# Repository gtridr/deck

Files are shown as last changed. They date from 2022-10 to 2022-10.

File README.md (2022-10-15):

# deck
An integrated instrument &amp; control surface based on norns

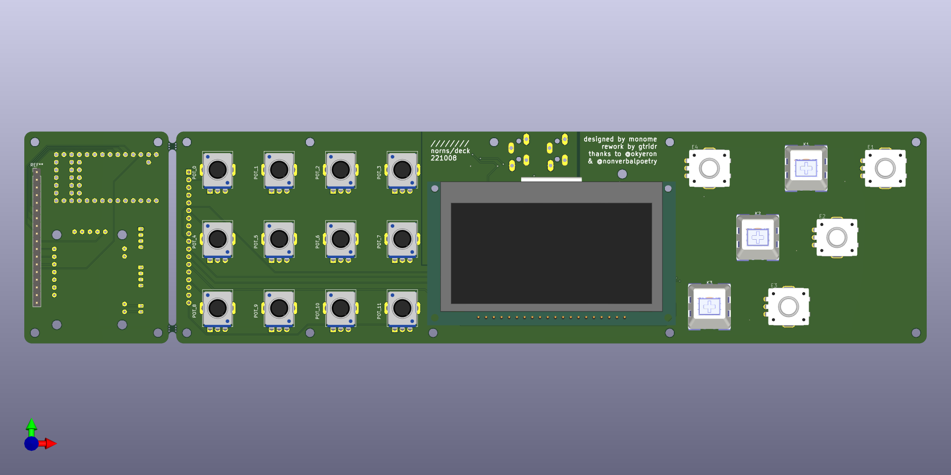
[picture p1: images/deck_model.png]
3D


## Credits & Licensing

Starting things off: this project is licensed as a derivative work under GPL-3.0. All due credits to the following individuals & projects:

 - The core audio codec & voltage regulation design are unmodified from the 210330 revision of the [norns shield](https://github.com/monome/norns-shield) save for some rerouting & cleanup

 - The raspberry pi image is a very lightly modified fork of the mainline norns codebase, with just a few tweaks to map the 4th encoder, serial pins for MICROMIDITRS, and soft shutdown via ATXRaspi.

 - The teensy firmware is a fork of Okyeron's [DIY grid](https://github.com/okyeron/neotrellis-monome) firmware. All credit for the grid emulation goes to him; I've only added what was necessary to get the potentiometers working over USB MIDI

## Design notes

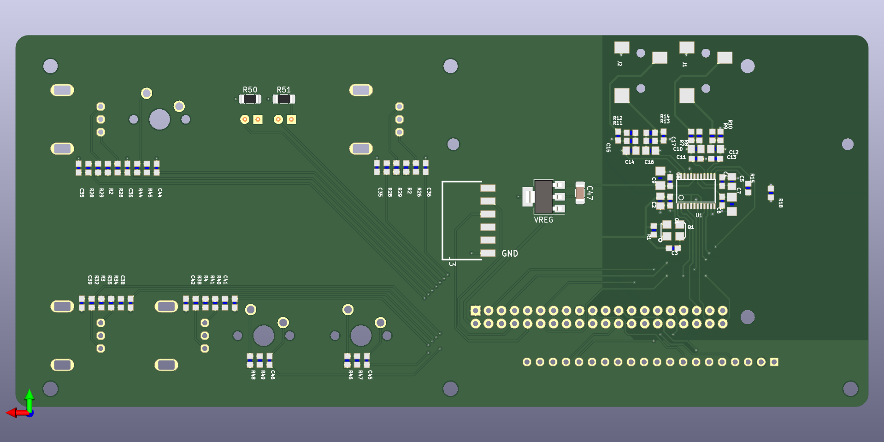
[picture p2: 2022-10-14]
images/Original/3d_back.png

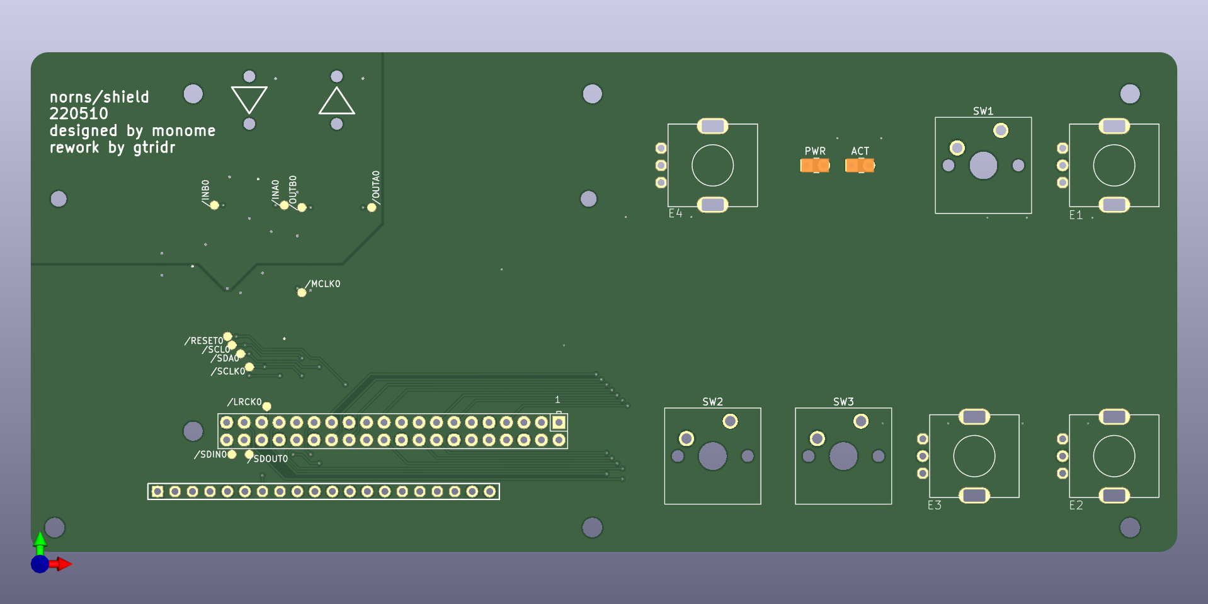
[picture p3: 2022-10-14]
images/Original/3d.png

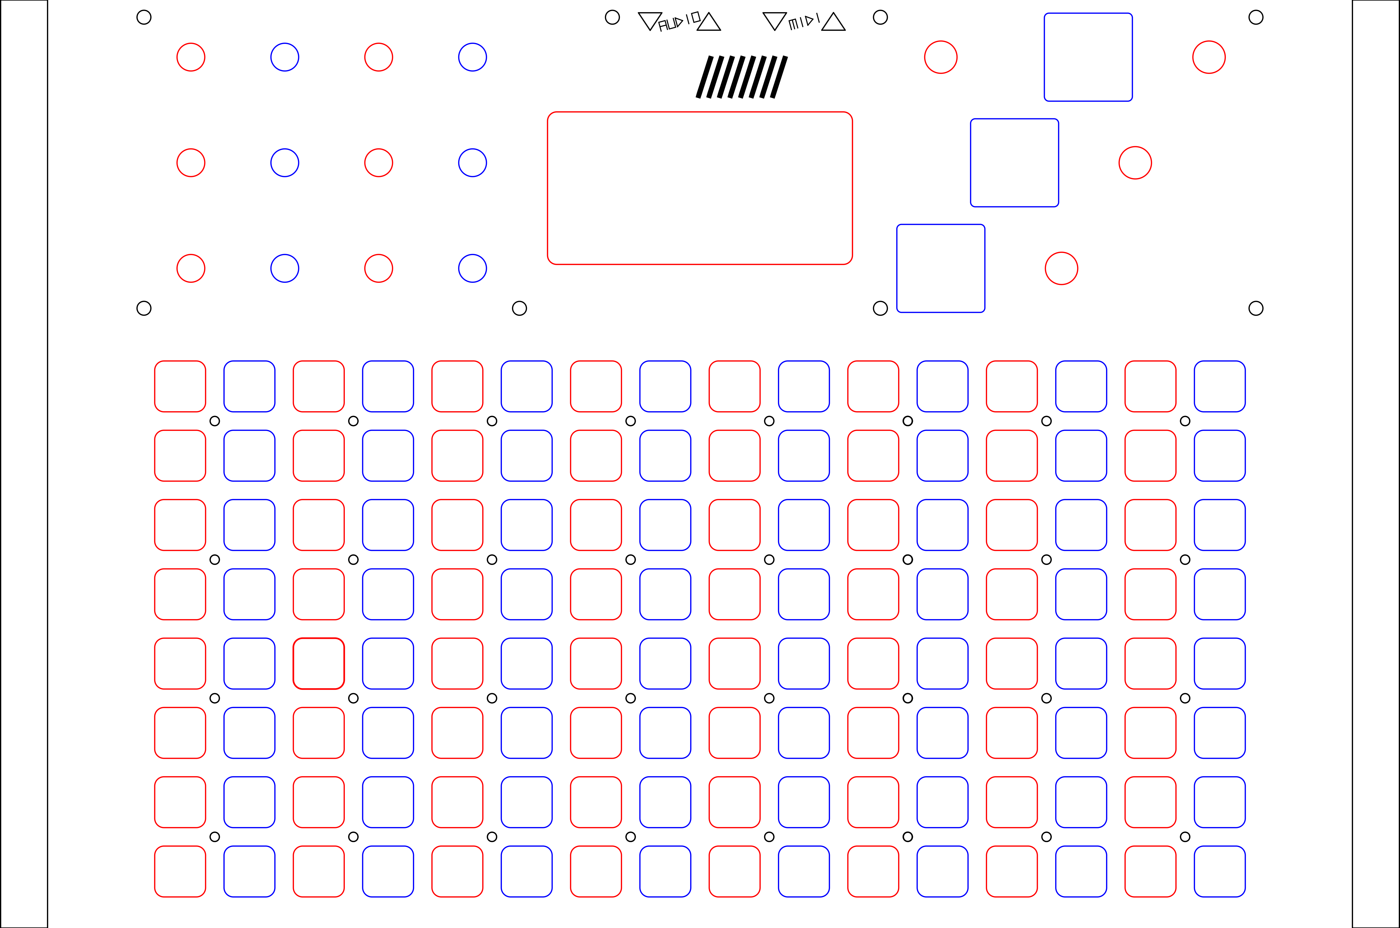
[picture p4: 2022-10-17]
images/deck_panel.png

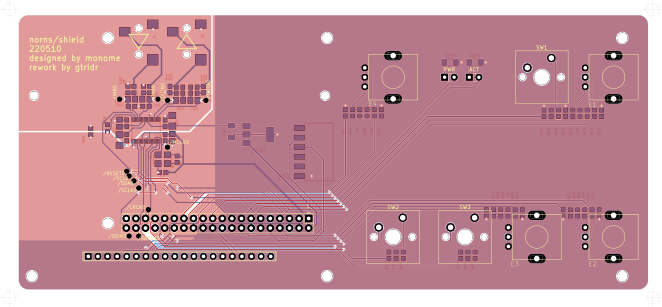
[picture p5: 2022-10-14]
images/Original/g7782.png

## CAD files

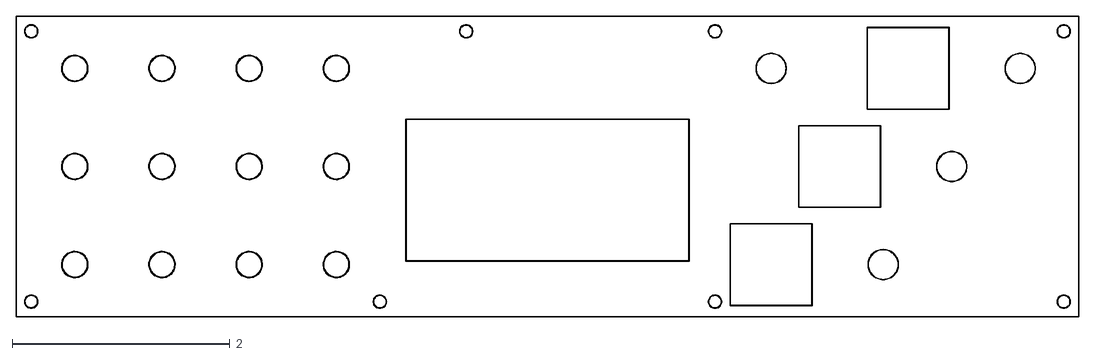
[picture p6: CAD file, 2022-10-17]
Enclosure/deck_outline.dxf
9.75 x 2.76

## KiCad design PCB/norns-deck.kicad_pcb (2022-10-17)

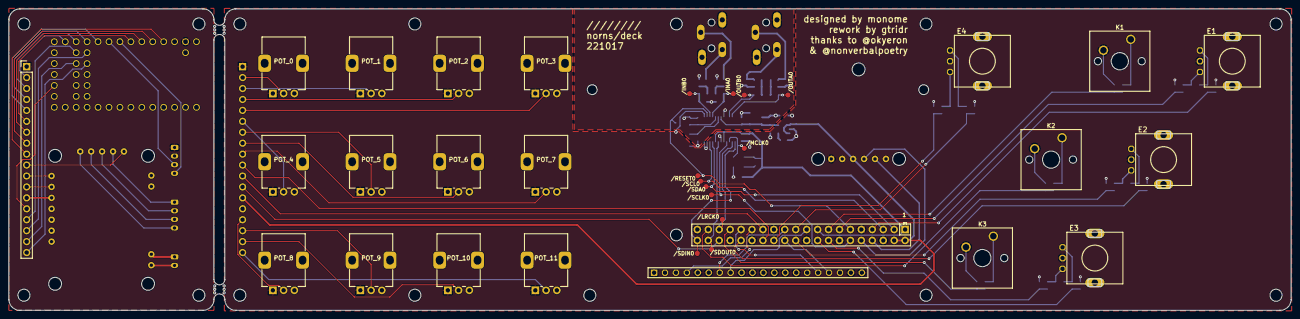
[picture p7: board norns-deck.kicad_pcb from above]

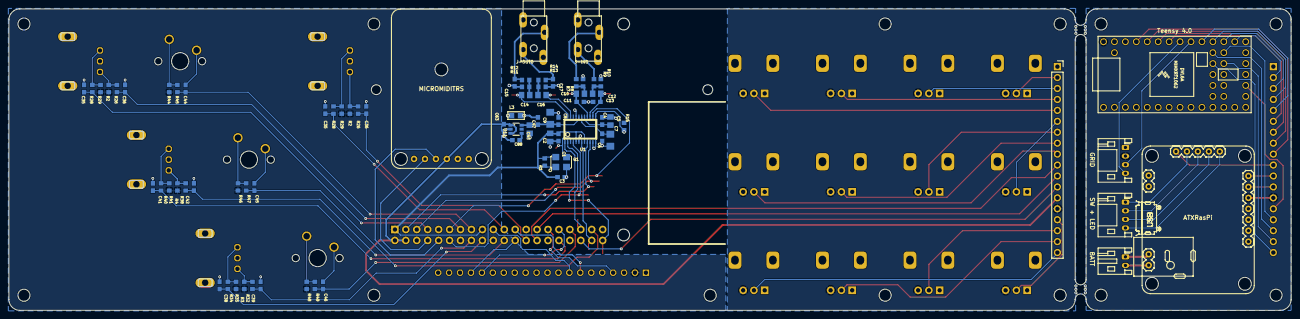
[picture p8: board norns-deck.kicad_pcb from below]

Board: 2 copper layers, 297.8 x 70.0 mm, 118 parts (76 on the bottom side), 80 nets.

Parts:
/INA0: TPTP12R; TP12R
/INB0: TPTP12R; TP12R
/LRCK0: TPTP12R; TP12R
/MCLK0: TPTP12R; TP12R
/OUTA0: TPTP12R; TP12R
/OUTB0: TPTP12R; TP12R
/RESET0: TPTP12R; TP12R
/SCL0: TPTP12R; TP12R
/SCLK0: TPTP12R; TP12R
/SDA0: TPTP12R; TP12R
/SDIN0: TPTP12R; TP12R
/SDOUT0: TPTP12R; TP12R
ATXRasPi: ATXRaspi
BATT: JST_PH_S2B-PH-K_1x02_P2.00mm_Horizontal
C1, C4, C6, C8, C47, C63: 100n; C0603
C2, C5, C10, C12, C43: 10u; C0805
C3, C35, C35#2, C36, C36#2, C38, C39, C41, C42, C44, C45, C46, C88: 10n; C0603
C7, C9: 47u; C1206
C11, C13: 220p COG; C0603
C14, C16: 3.3u; C0805
C15, C17: 2700p COG; C0603
DAUGHTERBOARD: PinSocket_1x18_P2.54mm_Vertical
E1: ENC1; PEC11RN
E2: ENC2; PEC11RN
E3: ENC3; PEC11RN
E4: ENC4; PEC11RN
GRID: JST_PH_S4B-PH-K_1x04_P2.00mm_Horizontal
J-IN0: JACK-TRS-SW; JACK4832.2330
J-OUT0: JACK-TRS-SW; JACK4832.2330
K1, K2, K3: SW_Cherry_MX_1.00u_PCB_NO_OUTLINE; SW_Cherry_MX_1.00u_PCB_NARROW_OUTLINE
L3: FERRITE; L0805
MICROMIDITRS: MICROMIDITRS
MNT: mounting hole
MNT#2, MNT#3, MNT#4, MNT#5, MNT#6: mounting hole
POT_0, POT_1, POT_2, POT_3, POT_4, POT_5, POT_6, POT_7, POT_8, POT_9, POT_10, POT_11: Potentiometer_Alps_RK09K_Single_Vertical
Q1: ASFL-12.288mhz; ASF
R1, R2, R2#2, R3, R4, R8, R10, R11, R13, R15, R26, R26#2, R28, R28#2, R29, R29#2, R32, R34, R35, R38, R40, R41, R44, R45, R46, R47, R48, R49: 10k; R0603
R7, R9: 4.99k; R0603
R12, R14: 590; R0603
SW + LED: JST_PH_S4B-PH-K_1x04_P2.00mm_Horizontal
Teensy 4.0: Teensy 4.0; Teensy40
U1: CS4270; TSSOP24
U11: TPS793; SSOP6
U$1: OLED128X64; OLED-ALEPH
X1: RASPI_BOARD_B+#_E3; RASPI_BOARD_B+_EDGES_3DRILL
mouse-bite-2.54mm-slot, mouse-bite-2.54mm-slot#2: VAL**; mouse-bite-2.54mm-slot

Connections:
+3V3: C1.1, C2.1, C3.1, Q1.4, R1.1, R2.2, R2#2.2, R3.2, R4.2, R29.2, R29#2.2, R35.2, R41.2, R44.1, R46.1, R48.1, U1.5, U1.8, U$1.2, X1.1, X1.17
+5V: ATXRasPi.9, C63.1, DAUGHTERBOARD.13, GRID.2, MICROMIDITRS.3, Teensy 4.0.33, U11.1, U11.3, X1.2, X1.4
A1: C35#2.1, R28#2.2, X1.7
A2: C41.1, R40.2, X1.32
A3: C38.1, R34.2, X1.18
A4: C35.1, R28.2, X1.21
A5V: C8.1, C9.1, C43.1, C47.1, U1.19, U11.6
AGND: C4.2, C5.2, C6.2, C7.2, C8.2, C9.2, C11.2, C13.2, C15.2, C17.2, C47.2, J-IN0.S, J-IN0.SW, J-OUT0.S, J-OUT0.SW, L3.1, R8.2, R10.2, R11.2, R13.2, U1.20
ATX1: DAUGHTERBOARD.10, X1.28
ATX2: DAUGHTERBOARD.11, X1.27
ATX3: DAUGHTERBOARD.12, X1.36
B1: C36.1, R26.2, X1.13
B2: C42.1, R38.2, X1.22
B3: C39.1, R32.2, X1.16
B4: C36#2.1, R26#2.2, X1.26
BAT+: ATXRasPi.14, BATT.2
BAT-: ATXRasPi.15, BATT.1
CE0: U$1.17, X1.24
GND: C1.2, C2.2, C3.2, C35.2, C35#2.2, C36.2, C36#2.2, C38.2, C39.2, C41.2, C42.2, C43.2, C44.2, C45.2, C46.2, C63.2, C88.2, DAUGHTERBOARD.1, E1.GND, E2.GND, E3.GND, GRID.1, K1.2, K2.2, K3.2, L3.2, MICROMIDITRS.1, POT_0.1, POT_1.1, POT_2.1, POT_3.1, POT_4.1, POT_5.1, POT_6.1, POT_7.1, POT_8.1, POT_9.1, POT_10.1, POT_11.1, Q1.2, R15.2, Teensy 4.0.32, U1.6, U1.11, U1.12, U1.13, U11.2, U$1.1, U$1.5, U$1.6, U$1.9, U$1.10, U$1.11, U$1.12, U$1.13, U$1.14, U$1.19, U$1.20, X1.6, X1.9, X1.14, X1.20, X1.25, X1.30, X1.34, X1.39
INA: /INA0.TP, C10.1, C11.1, U1.16
INB: /INB0.TP, C12.1, C13.1, U1.15
K1: C44.1, R45.2, X1.15
K2: C45.1, R47.2, X1.37
K3: C46.1, R49.2, X1.33
LED+: ATXRasPi.5, SW + LED.4
LED-: ATXRasPi.4, SW + LED.3
LRCK: /LRCK0.TP, U1.2, X1.35
MCLK: /MCLK0.TP, Q1.3, U1.3
MOSI: U$1.8, X1.19
unnamed: Q1.1, R1.2
unnamed: K1.1, R44.2, R45.1
unnamed: C4.1, C5.1, U1.17
unnamed: C6.1, C7.1, U1.18
unnamed: J-IN0.R, R7.2
unnamed: C10.2, R7.1, R8.1
unnamed: C12.2, R9.1, R10.1
unnamed: J-IN0.T, R9.2
unnamed: C16.2, R13.1, R14.1
unnamed: C14.2, R11.1, R12.1
unnamed: C15.1, J-OUT0.R, R12.2
unnamed: C17.1, J-OUT0.T, R14.2
unnamed: E1.A, R28#2.1, R29#2.1
unnamed: E1.B, R2.1, R26.1
unnamed: E3.B, R3.1, R32.1
unnamed: E3.A, R34.1, R35.1
unnamed: E2.B, R4.1, R38.1
unnamed: E2.A, R40.1, R41.1
unnamed: E4.A, R28.1, R29.1
unnamed: E4.B, R2#2.1, R26#2.1
unnamed: C88.1, U11.4
OUTA: /OUTA0.TP, C14.1, U1.23
OUTB: /OUTB0.TP, C16.1, U1.22
O_DC: U$1.4, X1.29
O_RESET: U$1.16, X1.31
R-CODEC: /RESET0.TP, R15.1, U1.14, X1.11
RX: MICROMIDITRS.4, X1.10
SCK: U$1.7, X1.23
SCL: /SCL0.TP, U1.10, X1.5
SCL0: GRID.4, Teensy 4.0.26
SCLK: /SCLK0.TP, U1.4, X1.12
SDA: /SDA0.TP, U1.9, X1.3
SDA0: GRID.3, Teensy 4.0.25
SDIN: /SDIN0.TP, U1.1, X1.40
SDOUT: /SDOUT0.TP, U1.7, X1.38
SW+: ATXRasPi.3, SW + LED.2
SW-: ATXRasPi.2, SW + LED.1
T+3v3: DAUGHTERBOARD.14, POT_0.3, POT_1.3, POT_2.3, POT_3.3, POT_4.3, POT_5.3, POT_6.3, POT_7.3, POT_8.3, POT_9.3, POT_10.3, POT_11.3, Teensy 4.0.16
TX: MICROMIDITRS.5, X1.8
p0: DAUGHTERBOARD.2, POT_0.2
p1: DAUGHTERBOARD.3, POT_1.2
p2: DAUGHTERBOARD.4, POT_2.2
p3: DAUGHTERBOARD.5, POT_3.2
p4: DAUGHTERBOARD.6, POT_4.2
p5: DAUGHTERBOARD.7, POT_5.2
p6: DAUGHTERBOARD.8, POT_6.2
p7: DAUGHTERBOARD.9, POT_7.2
p8: DAUGHTERBOARD.15, POT_8.2
p9: DAUGHTERBOARD.16, POT_9.2
p10: DAUGHTERBOARD.17, POT_10.2
p11: DAUGHTERBOARD.18, POT_11.2
